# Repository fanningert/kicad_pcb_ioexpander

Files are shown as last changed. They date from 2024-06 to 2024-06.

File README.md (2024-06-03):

# I²C IO-Expander



Core goal is a pcb with the same pin outs, but with different i²C IO Expander. Castellated holes with secondary pin header holes are added, for direct PCB soldering. Secondary pin header holes are placed in a matrix of 2,54 mm (100 mils). Because of the fixed pin layout of the pcb, I created the boards in a four layer design.

# Versions

## SX1509

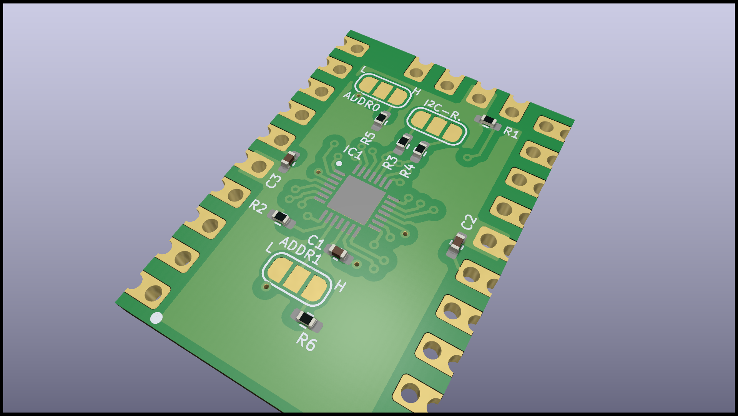
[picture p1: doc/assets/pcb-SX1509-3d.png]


## PCA9685

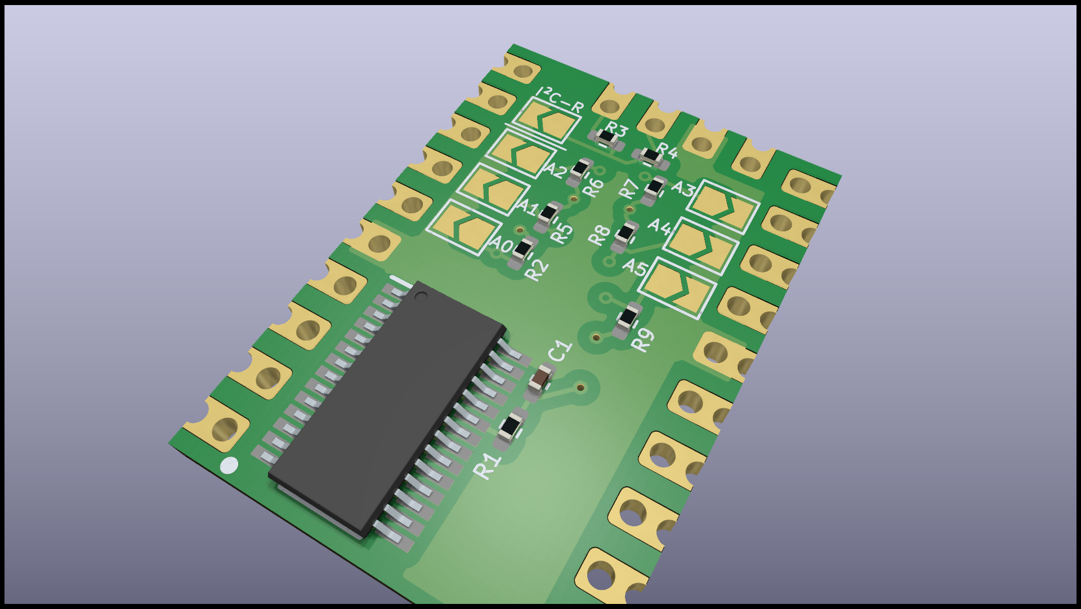
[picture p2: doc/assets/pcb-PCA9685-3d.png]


## Features

* Solder pads for I²C address
* Solder pads for I²C Pull-Up Resistor

## ToDos

* Create working GitHub workflow to create releases
* Optimize GitHub workflow for a more generic solution (no modification, when adding a new board)

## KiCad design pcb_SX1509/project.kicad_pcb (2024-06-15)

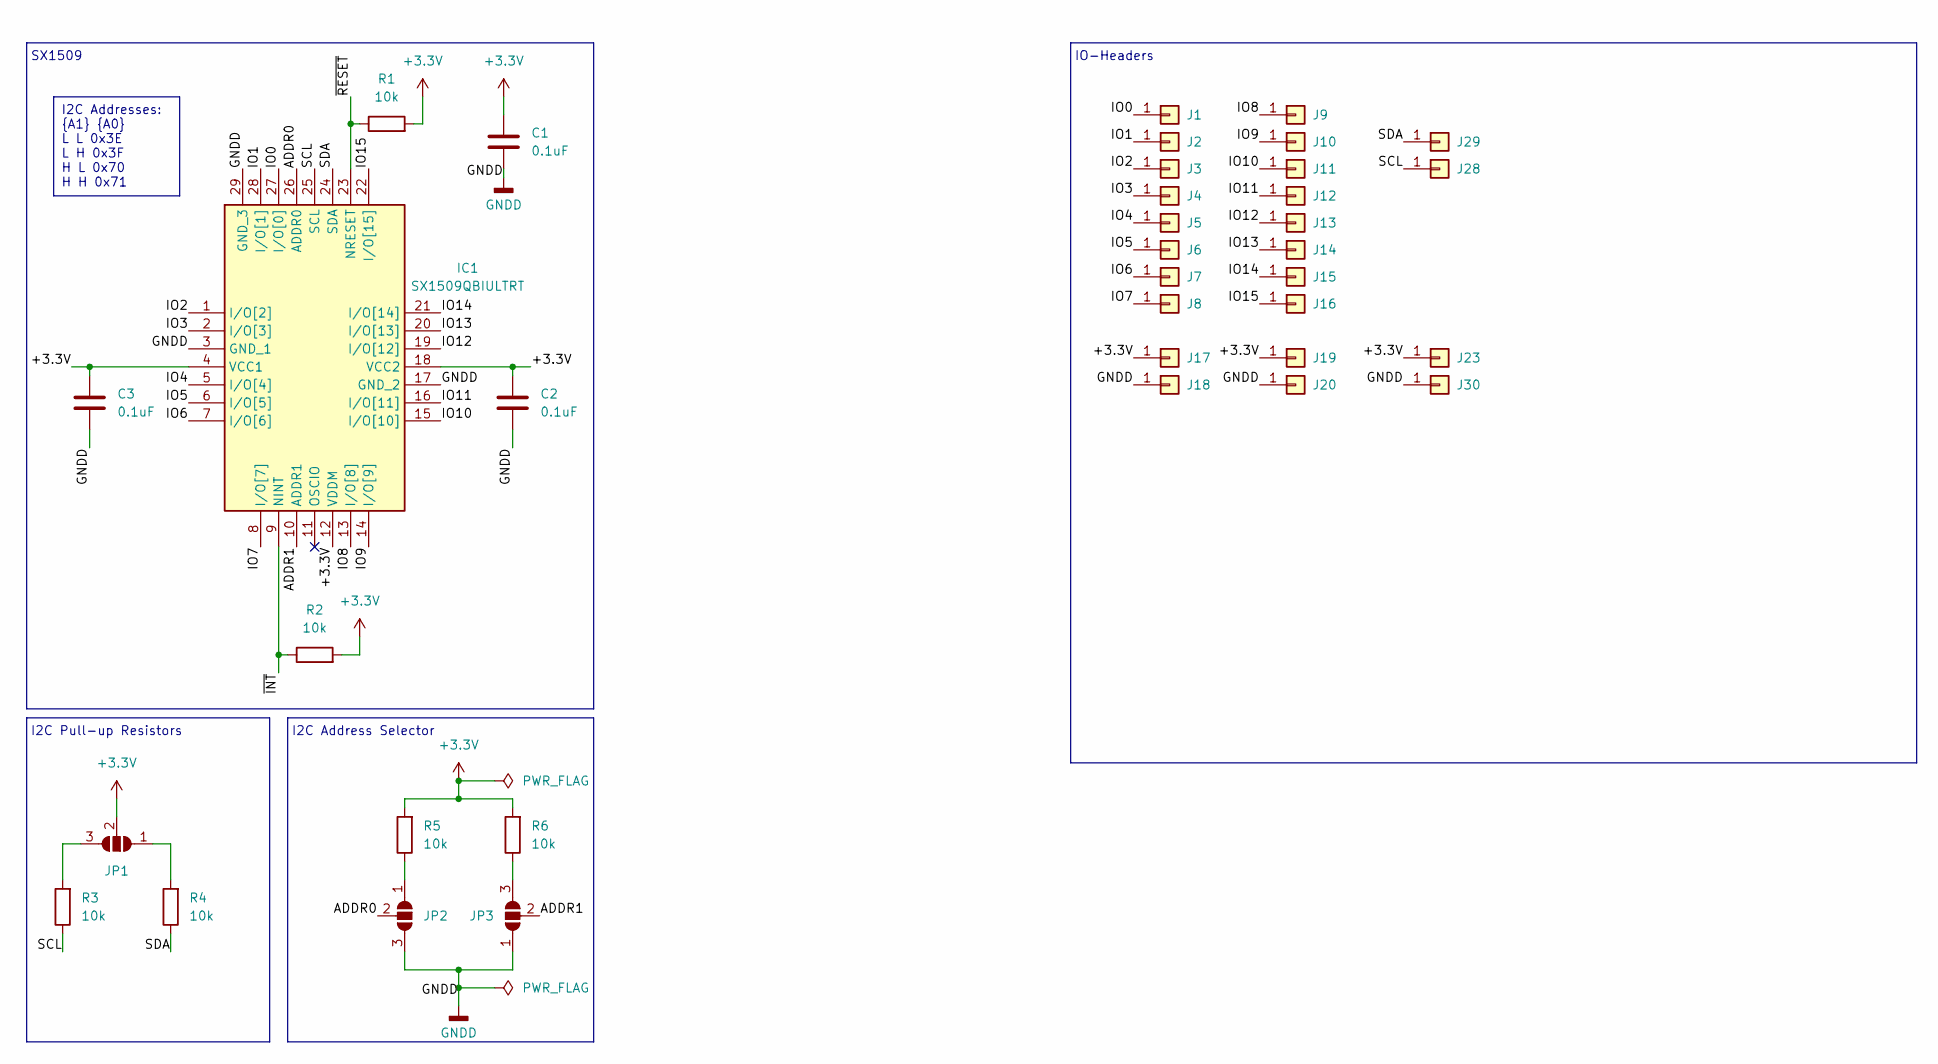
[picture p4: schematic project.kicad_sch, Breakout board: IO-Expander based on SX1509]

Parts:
C1, C2, C3: 0.1uF; C_0402_1005Metric_Pad0.74x0.62mm_HandSolder
IC1: SX1509QBIULTRT; QFN40P400X400X60-29N-D; Mouser Part Number 947-SX1509QBIULTRT
J1, J2, J3, J4, J5, J6, J7, J8, J9, J10, J11, J12, J13, J14, J15, J16, J17, J18, J19, J20, J23, J28, J29, J30: Castellated_Hole02
JP1, JP2, JP3: SolderJumper_3_Open; SolderJumper-3_P1.3mm_Open_RoundedPad1.0x1.5mm
R1, R2, R3, R4, R5, R6: 10k; R_0402_1005Metric_Pad0.72x0.64mm_HandSolder

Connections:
+3.3V: C1.1, C2.1, C3.1, IC1.4 (VCC1), IC1.12 (VDDM), IC1.18 (VCC2), J17.1, J19.1, J23.1, JP1.2 (C), R1.2, R2.2, R5.2, R6.2
/ADDR0: IC1.26 (ADDR0), JP2.2 (C)
/ADDR1: IC1.10 (ADDR1), JP3.2 (C)
/IO0: IC1.27 (I/O[0]), J1.1
/IO1: IC1.28 (I/O[1]), J2.1
/IO2: IC1.1 (I/O[2]), J3.1
/IO3: IC1.2 (I/O[3]), J4.1
/IO4: IC1.5 (I/O[4]), J5.1
/IO5: IC1.6 (I/O[5]), J6.1
/IO6: IC1.7 (I/O[6]), J7.1
/IO7: IC1.8 (I/O[7]), J8.1
/IO8: IC1.13 (I/O[8]), J9.1
/IO9: IC1.14 (I/O[9]), J10.1
/IO10: IC1.15 (I/O[10]), J11.1
/IO11: IC1.16 (I/O[11]), J12.1
/IO12: IC1.19 (I/O[12]), J13.1
/IO13: IC1.20 (I/O[13]), J14.1
/IO14: IC1.21 (I/O[14]), J15.1
/IO15: IC1.22 (I/O[15]), J16.1
/SCL: IC1.25 (SCL), J28.1, R3.1
/SDA: IC1.24 (SDA), J29.1, R4.1
/~INT: IC1.9 (NINT), R2.1
/~RESET: IC1.23 (NRESET), R1.1
GNDD: C1.2, C2.2, C3.2, IC1.3 (GND_1), IC1.17 (GND_2), IC1.29 (GND_3), J18.1, J20.1, J30.1, JP2.3 (B), JP3.1 (A)
unnamed: JP1.1 (A), R4.2
unnamed: JP1.3 (B), R3.2
unnamed: JP2.1 (A), R5.1
unnamed: JP3.3 (B), R6.1

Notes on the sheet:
I2C Addresses: {A1} {A0} L L 0x3E L H 0x3F H L 0x70 H H 0x71
IO-Headers
I2C Address Selector
I2C Pull-up Resistors
SX1509

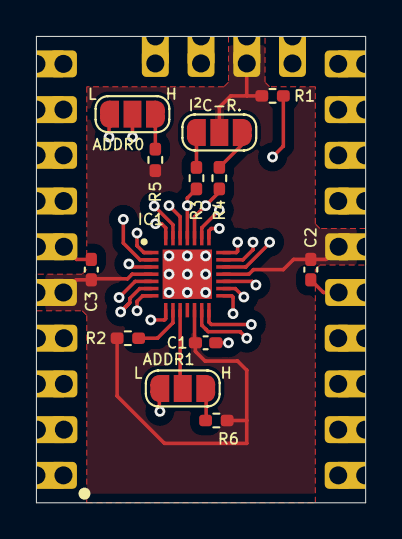
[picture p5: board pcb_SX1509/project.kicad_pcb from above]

Board: 4 copper layers, 18.3 x 25.9 mm, 38 parts (1 on the bottom side), 28 nets.

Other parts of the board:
QR*****: https://github.com/fanningert/kicad_pcb_ioexpander; //github.com/fanningert/kicad_pcb_ioexpander

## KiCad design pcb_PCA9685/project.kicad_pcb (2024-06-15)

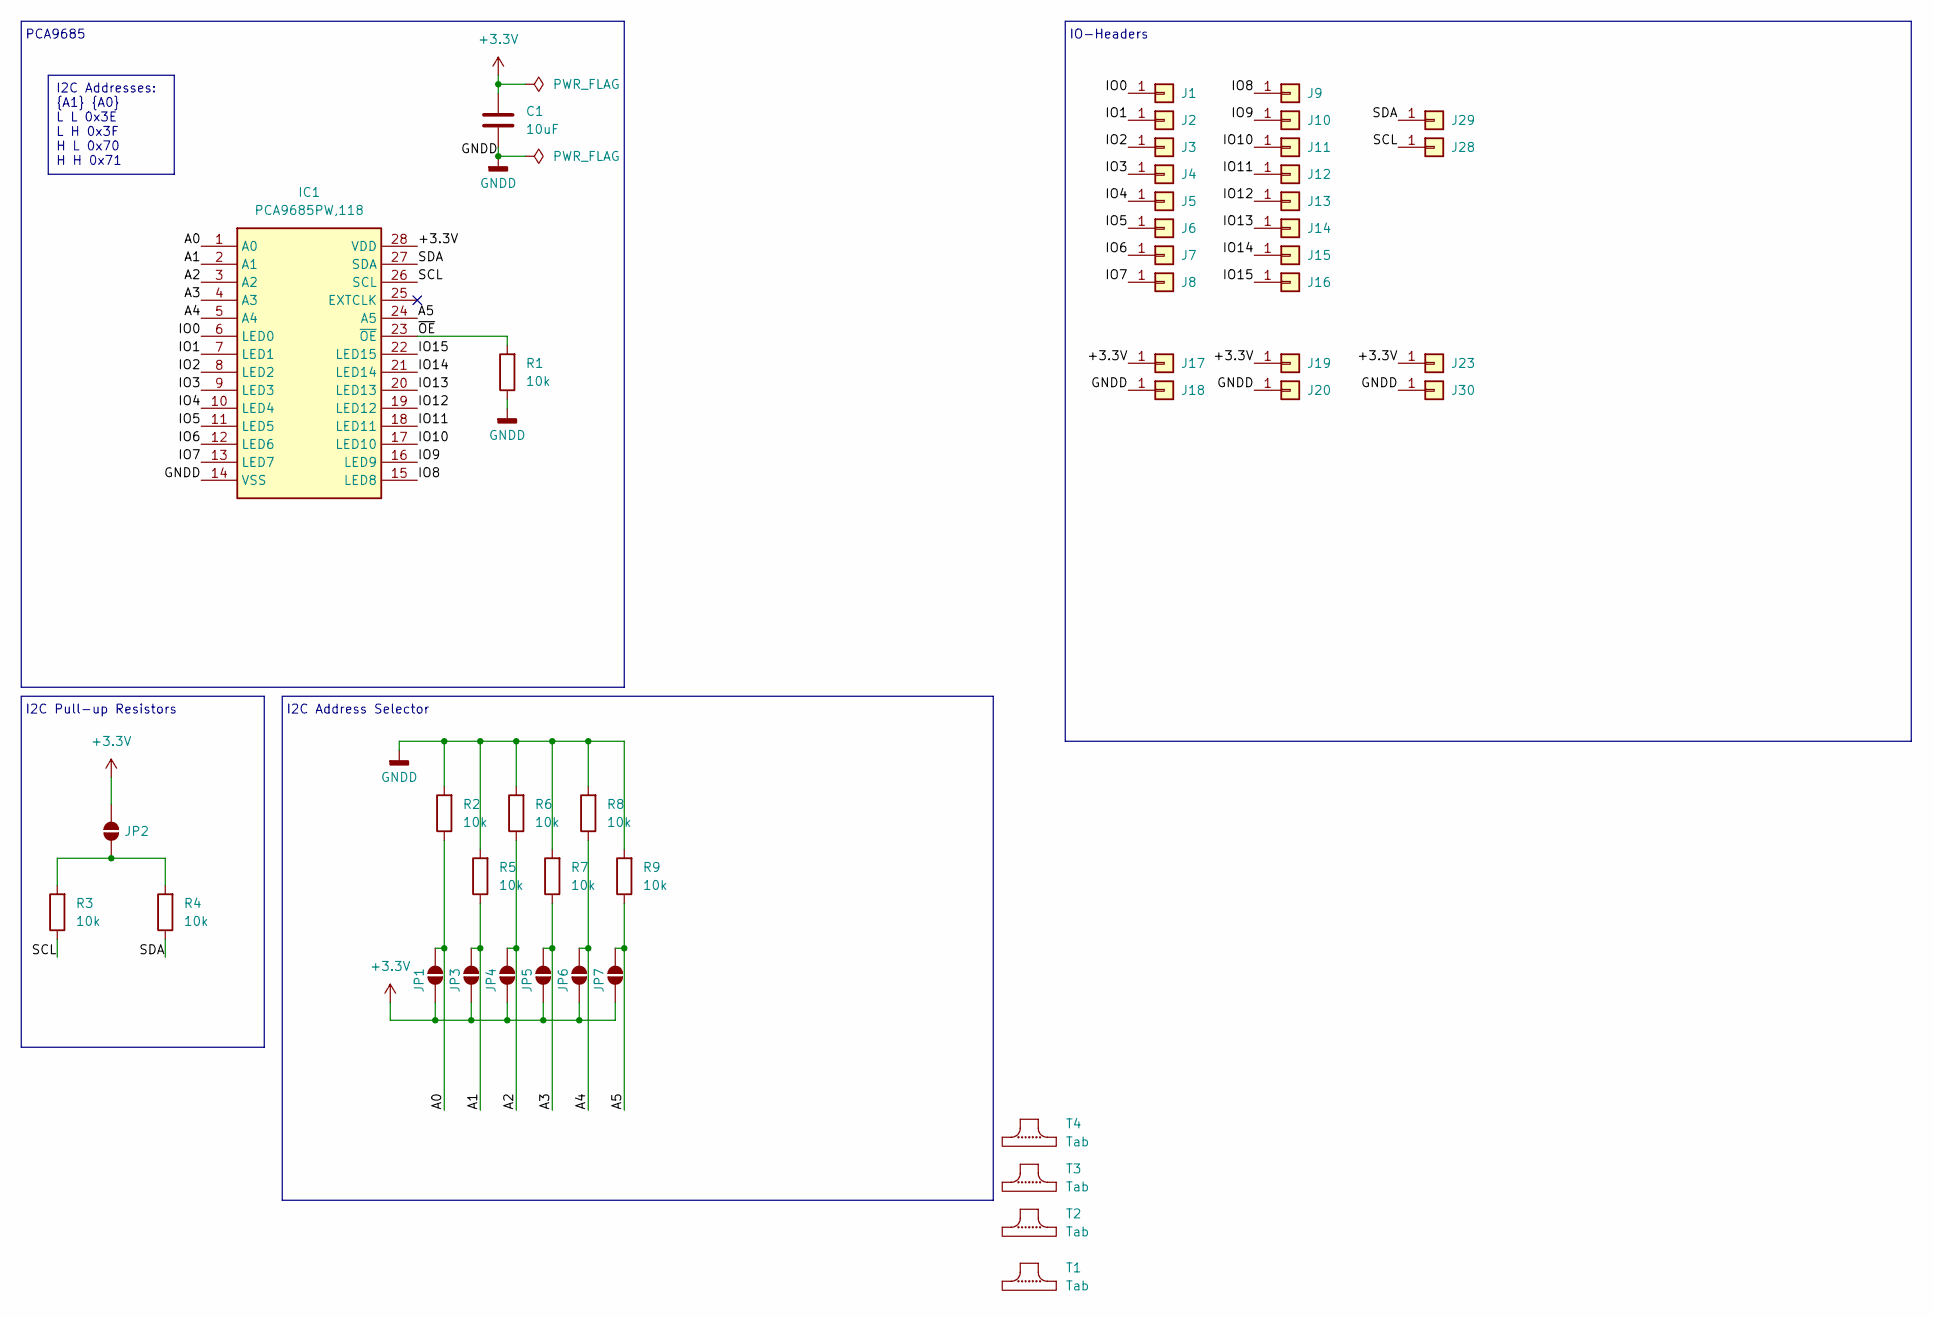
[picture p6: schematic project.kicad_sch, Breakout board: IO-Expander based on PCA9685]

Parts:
C1: 10uF; C_0402_1005Metric_Pad0.74x0.62mm_HandSolder
IC1: PCA9685PW,118; SOP65P640X110-28N; Mouser Part Number 771-PCA9685PW,118
J1, J2, J3, J4, J5, J6, J7, J8, J9, J10, J11, J12, J13, J14, J15, J16, J17, J18, J19, J20, J23, J28, J29, J30: Castellated_Hole02
JP1, JP2, JP3, JP4, JP5, JP6, JP7: SolderJumper_2_Open; SolderJumper-2_P1.3mm_Open_TrianglePad1.0x1.5mm
R1, R2, R3, R4, R5, R6, R7, R8, R9: 10k; R_0402_1005Metric_Pad0.72x0.64mm_HandSolder
T1, T2, T3, T4: Tab

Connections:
+3.3V: C1.1, IC1.28 (VDD), J17.1, J19.1, J23.1, JP1.2 (B), JP2.2 (B), JP3.2 (B), JP4.2 (B), JP5.2 (B), JP6.2 (B), JP7.2 (B)
/A0: IC1.1 (A0), JP1.1 (A), R2.1
/A1: IC1.2 (A1), JP3.1 (A), R5.1
/A2: IC1.3 (A2), JP4.1 (A), R6.1
/A3: IC1.4 (A3), JP5.1 (A), R7.1
/A4: IC1.5 (A4), JP6.1 (A), R8.1
/A5: IC1.24 (A5), JP7.1 (A), R9.1
/IO0: IC1.6 (LED0), J1.1
/IO1: IC1.7 (LED1), J2.1
/IO2: IC1.8 (LED2), J3.1
/IO3: IC1.9 (LED3), J4.1
/IO4: IC1.10 (LED4), J5.1
/IO5: IC1.11 (LED5), J6.1
/IO6: IC1.12 (LED6), J7.1
/IO7: IC1.13 (LED7), J8.1
/IO8: IC1.15 (LED8), J9.1
/IO9: IC1.16 (LED9), J10.1
/IO10: IC1.17 (LED10), J11.1
/IO11: IC1.18 (LED11), J12.1
/IO12: IC1.19 (LED12), J13.1
/IO13: IC1.20 (LED13), J14.1
/IO14: IC1.21 (LED14), J15.1
/IO15: IC1.22 (LED15), J16.1
/SCL: IC1.26 (SCL), J28.1, R3.1
/SDA: IC1.27 (SDA), J29.1, R4.1
/~OE: IC1.23 (~OE), R1.2
GNDD: C1.2, IC1.14 (VSS), J18.1, J20.1, J30.1, R1.1, R2.2, R5.2, R6.2, R7.2, R8.2, R9.2
unnamed: JP2.1 (A), R3.2, R4.2

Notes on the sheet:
I2C Addresses: {A1} {A0} L L 0x3E L H 0x3F H L 0x70 H H 0x71
IO-Headers
I2C Address Selector
I2C Pull-up Resistors
PCA9685

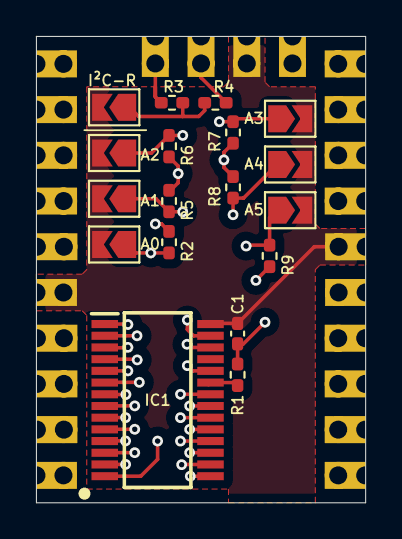
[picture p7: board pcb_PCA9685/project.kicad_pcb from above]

Board: 4 copper layers, 18.3 x 25.9 mm, 47 parts (1 on the bottom side), 28 nets.

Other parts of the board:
QR*****: https://github.com/fanningert/kicad_pcb_ioexpander; //github.com/fanningert/kicad_pcb_ioexpander

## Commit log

2024-06-01 Update kitbot config
    [project.kicad_pcb]
2024-06-02 Update PCB with infos
    [project.kicad_pcb, project.kicad_sch]
2024-06-02 Optimize pcb layout
    [project.kicad_pcb]
2024-06-02 Standard output pin design for SX1509 PCB and add a new variant based on PCA9685
    [project.kicad_pcb, project.kicad_sch]
2024-06-02 removed space in directory name
    [project.kicad_pcb, project.kicad_sch]
2024-06-03 Update PCB for PCA9685
    [project.kicad_pcb, project.kicad_sch]
2024-06-03 Add barcode with the GitHub repository URL on the backsite of the PCBs
    [project.kicad_pcb]
2024-06-03 Replace QRCode with better version
    [project.kicad_pcb]
2024-06-04 Remove connector on own side
    [project.kicad_pcb, project.kicad_sch]
2024-06-04 Replace resistor array throw single resistor for reducing vias dn easy component selection
    [project.kicad_pcb, project.kicad_sch]
2024-06-04 Remove qrcode from bom
    [project.kicad_pcb]
2024-06-09 Add panelize
    [project.kicad_pcb]
2024-06-09 Add generation of extra files for panlized PCB
2024-06-09 Correct some warnings and missing 3D step files
    [project.kicad_pcb, project.kicad_sch]
2024-06-09 Removed not needed text
    [project.kicad_pcb]
2024-06-09 Add revision number to PCB
    [project.kicad_pcb, project.kicad_sch]
2024-06-13 Correct kibot for four layer
    [project.kicad_pcb, project.kicad_sch]
2024-06-15 Test kiBot configuration with multi layer PCB
